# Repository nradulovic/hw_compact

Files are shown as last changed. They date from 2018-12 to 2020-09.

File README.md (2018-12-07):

Compact amplifier
=================

This amplifier is intended to be used as a small desktop amplifier. It has no
fancy stuff. It does not even have a volume knob.

It has a short-circuit protection and all the necessary filtering on the inputs
and outputs.

The input is single-ended. 

It has two types of boards:
 - Amplifier board: Mono channel.
 - Power supply board with speaker protection & mute and LED indication.

The complete model of the amplifier case layout is based on Dayens Ampino power 
amplifier.

Amplifier board
===============

Description
-----------

The board contains one amplifier with short-circuit proction and input and
output filters.

Dimensions
----------

Max width: 80mm
Max height: 100mm

Connections
-----------

* Power supply connectors: Vcc, GND, Vee.
* Output connectors: Out, GND.
* Input connector: In, SGND.

Power supply board
==================

Description
-----------

Dimensions
----------

Max width: 140mm
Max height: 100mm

Connections
-----------

* AC Voltage input: Live, Neutral, Earth.
* Switch: CN1, CN2.
* Primary output: Live, Neutral, Earth.
* Secondary input: AC1, GND, AC2.
* DC output: Vcc, GND, Vee.
* Amplifier input: OutL, GND, OutR, GND
* Amplifier output: OutL, GND, OutR, GND
* LED indicator (POWER/FAILURE/OVERLOAD): Anode, Cathode.
* Mute key: K1, K2.

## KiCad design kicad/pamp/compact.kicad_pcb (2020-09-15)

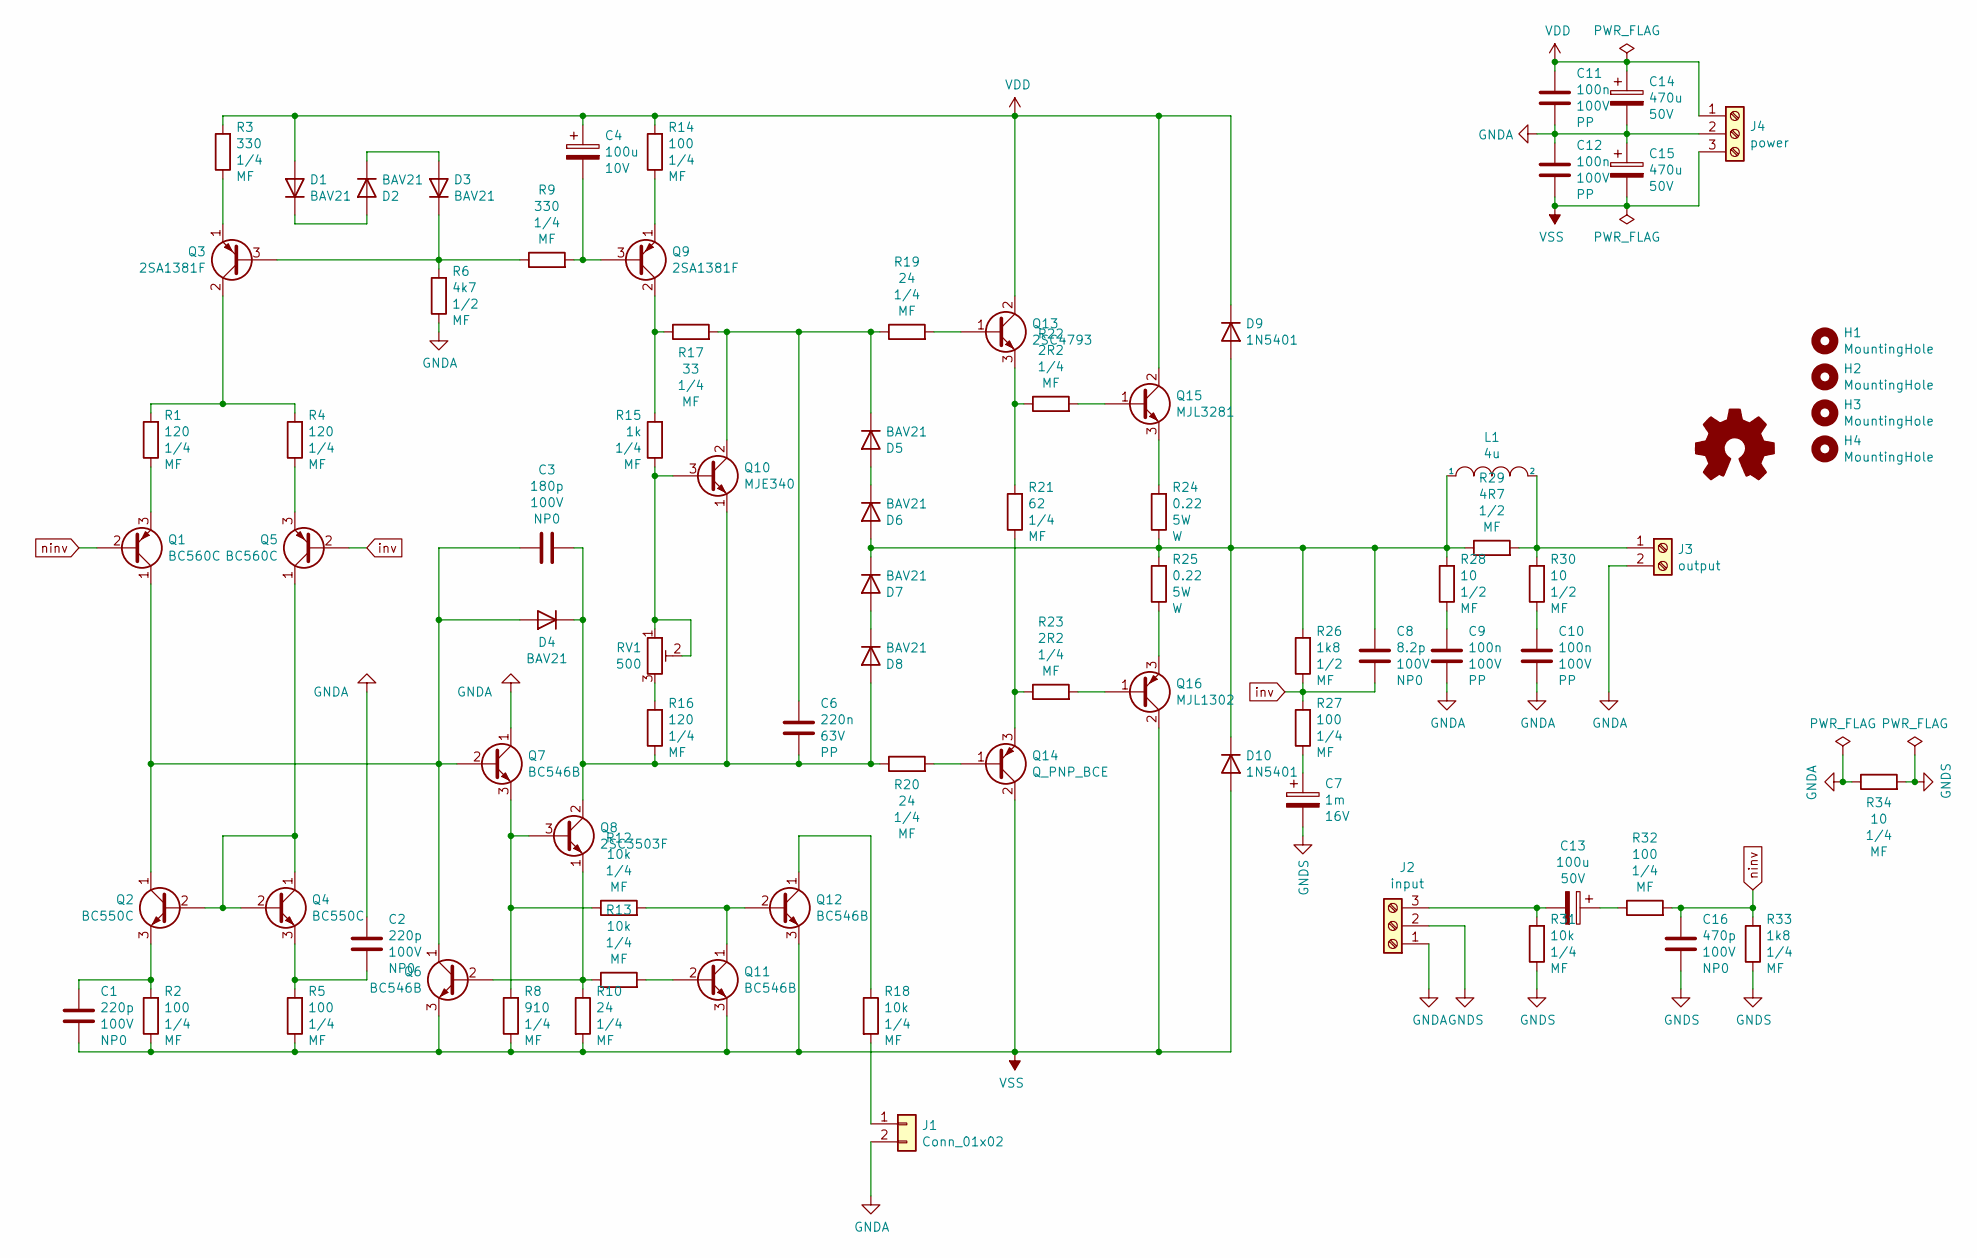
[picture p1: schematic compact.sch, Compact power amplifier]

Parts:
C1, C2: 220p; C_Disc_D8.0mm_W2.5mm_P5.00mm; Voltage 100V
C3: 180p; C_Disc_D8.0mm_W2.5mm_P5.00mm; Voltage 100V
C4: 100u; CP_Radial_D8.0mm_P2.50mm; Voltage 10V
C6: 220n; C_Rect_L7.2mm_W4.5mm_P5.00mm_FKS2_FKP2_MKS2_MKP2; Voltage 63V
C7: 1m; CP_Radial_D10.0mm_P3.50mm; Voltage 16V
C8: 8.2p; C_Disc_D3.0mm_W2.0mm_P2.50mm; Voltage 100V
C9, C10, C11, C12: 100n; C_Rect_L7.2mm_W5.5mm_P5.00mm_FKS2_FKP2_MKS2_MKP2; Voltage 100V
C13: 100u; CP_Radial_D10.0mm_P3.50mm; Voltage 50V
C14, C15: 470u; CP_Radial_D10.0mm_P3.50mm; Voltage 50V
C16: 470p; C_Disc_D8.0mm_W2.5mm_P5.00mm; Voltage 100V
D1, D2, D3, D4, D5, D6, D7, D8: BAV21; D_DO-41_SOD81_P7.62mm_Horizontal
D9, D10: 1N5401; D_DO-201AD_P15.24mm_Horizontal
H1, H2, H3, H4: MountingHole; MountingHole_3.2mm_M3_Pad
J1: Conn_01x02; PinHeader_1x02_P2.54mm_Vertical
J2: input; TerminalBlock_Phoenix_PT-1,5-3-3.5-H_1x03_P3.50mm_Horizontal
J3: output; PhoenixContact_MCV_1,5_2-G-3.81_1x02_P3.81mm_Vertical
J4: power; PhoenixContact_MCV_1,5_3-G-3.81_1x03_P3.81mm_Vertical
L1: 4u; L_Axial_L29.9mm_D14.0mm_P7.62mm_Vertical_Vishay_IHA-105
LOGO1: Logo_Open_Hardware_Small; KiCad-Logo_5mm_Copper
Q1, Q5: BC560C; TO-92L_Inline_Wide
Q2, Q4: BC550C; TO-92L_Inline_Wide
Q3: 2SA1381F; TO-126-3_Vertical
Q6, Q7, Q11, Q12: BC546B; TO-92L_Inline_Wide
Q8: 2SC3503F; TO-126-3_Horizontal_TabDown
Q9: 2SA1381F; TO-126-3_Horizontal_TabDown
Q10: MJE340; TO-126-3_Vertical
Q13: 2SC4793; TO-220-3_Vertical
Q14: Q_PNP_BCE; TO-220-3_Vertical
Q15: MJL3281; TO-264-3_Vertical
Q16: MJL1302; TO-264-3_Vertical
R1, R4, R16: 120; R_Axial_DIN0207_L6.3mm_D2.5mm_P10.16mm_Horizontal
R2, R5, R14, R27, R32: 100; R_Axial_DIN0207_L6.3mm_D2.5mm_P10.16mm_Horizontal
R3, R9: 330; R_Axial_DIN0207_L6.3mm_D2.5mm_P10.16mm_Horizontal
R6: 4k7; R_Axial_DIN0411_L9.9mm_D3.6mm_P12.70mm_Horizontal
R8: 910; R_Axial_DIN0207_L6.3mm_D2.5mm_P10.16mm_Horizontal
R10, R19, R20: 24; R_Axial_DIN0207_L6.3mm_D2.5mm_P10.16mm_Horizontal
R12, R13, R18, R31: 10k; R_Axial_DIN0207_L6.3mm_D2.5mm_P10.16mm_Horizontal
R15: 1k; R_Axial_DIN0207_L6.3mm_D2.5mm_P10.16mm_Horizontal
R17: 33; R_Axial_DIN0207_L6.3mm_D2.5mm_P10.16mm_Horizontal
R21: 62; R_Axial_DIN0207_L6.3mm_D2.5mm_P10.16mm_Horizontal
R22, R23: 2R2; R_Axial_DIN0207_L6.3mm_D2.5mm_P10.16mm_Horizontal
R24, R25: 0.22; R_Axial_Power_L20.0mm_W6.4mm_P25.40mm
R26: 1k8; R_Axial_DIN0411_L9.9mm_D3.6mm_P12.70mm_Horizontal
R28, R30: 10; R_Axial_DIN0411_L9.9mm_D3.6mm_P12.70mm_Horizontal
R29: 4R7; R_Axial_DIN0411_L9.9mm_D3.6mm_P12.70mm_Horizontal
R33: 1k8; R_Axial_DIN0207_L6.3mm_D2.5mm_P10.16mm_Horizontal
R34: 10; R_Axial_DIN0207_L6.3mm_D2.5mm_P10.16mm_Horizontal
RV1: 500; Potentiometer_ACP_CA9-V10_Vertical

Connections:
GNDA: C2.2, C9.2, C10.2, C11.2, C12.1, C14.2, C15.1, J1.2, J2.1, J3.2, J4.2, Q7.1 (C), R6.1, R34.1
GNDS: C7.2, C16.1, J2.2, R31.1, R33.1, R34.2
unnamed: C1.2, Q2.3 (E), R2.2
unnamed: C2.1, Q4.3 (E), R5.2
unnamed: C3.1, C6.2, D4.1 (K), D8.2 (A), Q8.2 (C), Q10.1 (E), R16.1, R20.1
unnamed: C3.2, D4.2 (A), Q1.1 (C), Q2.1 (C), Q6.1 (C), Q7.2 (B)
unnamed: C4.2, Q9.3 (B), R9.2
unnamed: C6.1, D5.1 (K), Q10.2 (C), R17.2, R19.1
unnamed: C7.1, R27.1
unnamed: C8.1, D6.2 (A), D7.1 (K), D9.2 (A), D10.1 (K), L1.1, R24.1, R25.2, R26.2, R28.2, R29.1
unnamed: C9.1, R28.1
unnamed: C10.1, R30.1
unnamed: C13.1, R32.1
unnamed: C13.2, J2.3, R31.2
unnamed: D1.1 (K), D2.2 (A)
unnamed: D2.1 (K), D3.2 (A)
unnamed: D3.1 (K), Q3.3 (B), R6.2, R9.1
unnamed: D5.2 (A), D6.1 (K)
unnamed: D7.2 (A), D8.1 (K)
unnamed: J1.1, R18.2
unnamed: J3.1, L1.2, R29.2, R30.2
unnamed: Q1.3 (E), R1.1
unnamed: Q2.2 (B), Q4.1 (C), Q4.2 (B), Q5.1 (C)
unnamed: Q3.1 (E), R3.1
unnamed: Q3.2 (C), R1.2, R4.2
unnamed: Q5.3 (E), R4.1
unnamed: Q6.2 (B), Q8.1 (E), R10.1, R13.1
unnamed: Q7.3 (E), Q8.3 (B), R8.2, R12.1
unnamed: Q9.1 (E), R14.1
unnamed: Q9.2 (C), R15.2, R17.1
unnamed: Q10.3 (B), R15.1, RV1.1, RV1.2
unnamed: Q11.1 (C), Q12.2 (B), R12.2
unnamed: Q11.2 (B), R13.2
unnamed: Q12.1 (C), R18.1
unnamed: Q13.1 (B), R19.2
unnamed: Q13.3 (E), R21.2, R22.1
unnamed: Q14.1 (B), R20.2
unnamed: Q14.3 (E), R21.1, R23.1
unnamed: Q15.1 (B), R22.2
unnamed: Q15.3 (E), R24.2
unnamed: Q16.1 (B), R23.2
unnamed: Q16.3 (E), R25.1
unnamed: R16.2, RV1.3
VDD: C4.1, C11.1, C14.1, D1.2 (A), D9.1 (K), J4.1, Q13.2 (C), Q15.2 (C), R3.2, R14.2
VSS: C1.1, C12.2, C15.2, D10.2 (A), J4.3, Q6.3 (E), Q11.3 (E), Q12.3 (E), Q14.2 (C), Q16.2 (C), R2.1, R5.1, R8.1, R10.2
inv: C8.2, Q5.2 (B), R26.1, R27.2
ninv: C16.2, Q1.2 (B), R32.2, R33.2

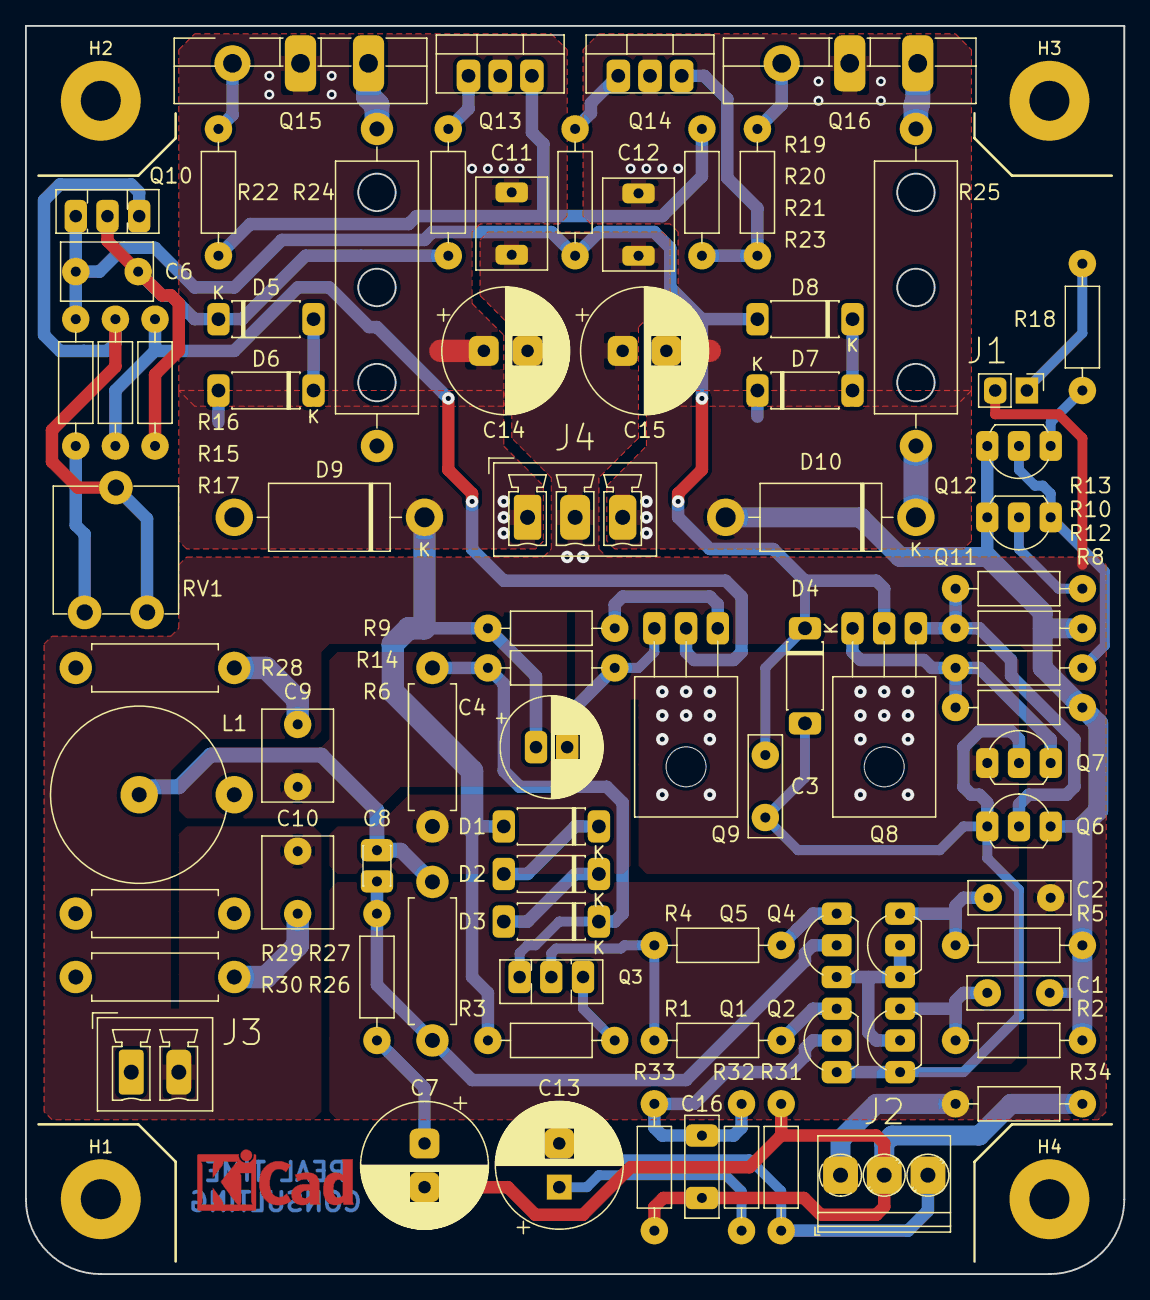
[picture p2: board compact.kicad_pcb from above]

Board: 2 copper layers, 88.0 x 100.0 mm, 84 parts (0 on the bottom side), 47 nets.

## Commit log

2018-12-07 Minor schematic rearranging
2018-12-10 Moved spice and kicad projects to their own folders.
    [compact.kicad_pcb, compact.sch]
2019-01-08 Using modular spice approach
    [compact.kicad_pcb, compact.sch]
2019-02-27 Updated .gitignore, vi limiter and MOSFET schematic
2019-03-05 Added protection pin, AC (gain&PSRR) evaluated
2019-04-15 WIP: Using symmetrical MOSFET design.
    [compact.sch]
2019-04-15 WIP: Started schematic.
    [compact.sch]
2019-04-15 WIP: Schematic is almost complete
    [compact.sch]
2019-04-16 Added all components.
    [compact.sch]
2019-04-16 WIP: Resolving ERC.
    [compact.sch]
2019-04-17 Completed schematic and part placement
    [compact.kicad_pcb, compact.sch]
2019-04-18 WIP: Done schematic.
    [compact.sch]
2019-07-26 The complete schematic design is almost complete.
2019-07-29 Minimal PCB version.
    [compact.kicad_pcb, compact.sch]
2019-08-03 First prerelease.
    [compact.kicad_pcb, compact.sch]
2020-09-15 Made the compensation scheme much simpler.
    [compact.kicad_pcb, compact.sch]
2021-07-25 feat: THD20 .005@16V
    [compact.kicad_pcb]
2021-07-26 Revert "feat: THD20 .005@16V"
    After evaluating simple architectures it was concluded that this complex
    architecture is not worth it.
    This reverts commit fa6ed1e580e39e242b81db925e514dbd501194ff.
    [compact.kicad_pcb]
2021-07-26 feat: THD1.002@16V
2021-08-18 feat: project organization
    [compact.sch]
